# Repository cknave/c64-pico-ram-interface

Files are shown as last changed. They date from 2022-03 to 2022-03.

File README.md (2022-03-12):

# Commodore 64 to Raspberry Pi Pico RAM interface

This project exposes a 16 KiB window of a Raspberry Pi Pico's RAM to a Commodore 64 via the
expansion port. It includes a hardware design and software for the Pico C++ SDK.

<table style="border-collapse: collapse"><tr>
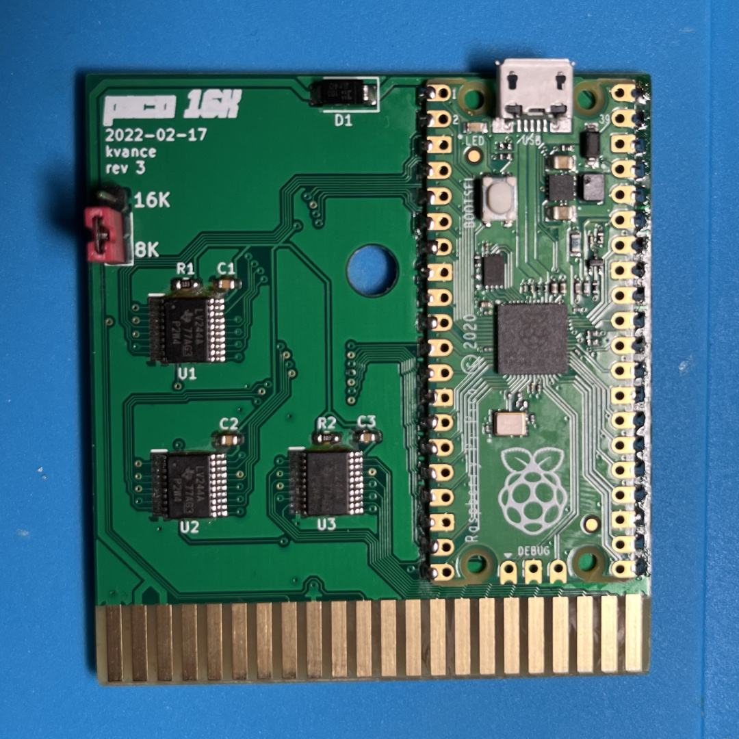
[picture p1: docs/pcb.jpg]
PCB photo
<td><figure>
<figcaption>PCB image</figcaption></figure></td>
<td><figure><a href="https://youtu.be/zC7R9OgKrbg">Demo video thumbnail</a>
<figcaption>Demo video</figcaption></figure>
</tr></table>

## The hardware

**[Schematic PDF](./docs/schematic.pdf)**

Schematic, PCB, and project files are in KiCad 6 format.

5V power from the expansion port is used to power the Pico. As suggested in the Pico datasheet,
a Schottky diode allows the Pico to be connected to powered USB at the same time. 

8-bit buffers bring the 5V logic levels on the address and data bus down to 3.3V to protect
the Pico's GPIO pins. This means that when the C64 reads from the Pico, it's putting a 3.3V
signal on the data bus.  At TTL logic levels, this should be fine.

A switch allows you to toggle between an 8K ROM and a 16K ROM by pulling the /GAME line low.
This loses half the address space, but lets you boot into BASIC.

The tolerances on the PCB design are compatible with [JLCPCB](https://jlcpcb.com/). I ordered
my prototypes from them with ENIG surface finish and gold fingers on a 1.6mm thick board.  You
can get them made much cheaper with HASL, but it will eventually scrape off as you reinsert
the board.

## The firmware

Given a 16 KiB-aligned base address on the Pico's address space, four PIO state machines and
two DMA channels handle reading addresses from the C64 address bus and writing the requested
data to the C64 data bus. The CPU is not needed once this is configured.

To allow the C64 to communicate with the Pico, a 256 byte **command area** is reserved that
will put that byte onto the RX FIFO for the CPU to consume.  The CPU can put any value onto
the TX FIFO to signal that it is ready for more commands.

Between the GPIO pins and the RAM, there are five logical components:

- **address_decoder PIO state machine:** monitors the /ROML and /ROMH lines for reads,
  checks if the address is for the special **command area**, and wakes up either the **read**
  or **command** state machines as needed.  Two copies of this state machine run at the same
  time, monitoring /ROML and /ROMH.
- **read PIO state machine:** reads the address lines, sends the address to DMA, and writes
  the returned data to the data bus
- **command PIO state machine:** reads the low 8 bits of the address, and copies it to the
  RX FIFO for the CPU to handle.  It writes the STATUS register back to the data bus, indicating
  if the CPU is busy or not. The CPU can indicate its readiness by writing any value to the TX FIFO.

  The special value `00` will not be sent to the CPU at all, allowing the C64 to poll the status
  register until the Pico is finished processing a command.
- **DMA channel 1**: write the incoming address to the configuration of DMA channel 2, triggering
  a read
- **DMA channel 2**: copy a byte at the requested RAM address to the read PIO state machine

Read sequence

Command sequence

It's a Rube Goldberg machine, but the Pico's PIO controllers and DMA can do this in well under
the time required by the C64's CPU.

## Further improvements

### Could this work as a 16K ROM and IO ports?

Maybe, but this design is already using all the GPIO pins on the Pico.  Even if you replace
the "input enable" pin (you can probably get away without it), you'll also need to monitor
PHI2.  In my experience, the IO lines are glitchy and you need to make sure that you're actually
in the right part of the clock cycle to use them.

You could try using a shift register to free up a bunch of pins, but you'll waste a lot of
PIO clock cycles shifting all the bits through it.  It might be fast enough to only shift a
couple of bits.

### Could I use all 44 KiB of the available address space?

I think you're definitely in shift register territory at this point, and good luck trying to
decode more than a couple of address prefixes in PIO.  If you actually do this, please contact
me because I want to see it!

## Legal

Distribute under the terms of the BSD 3-clause license.

The [KiCad-RP-Pico footprint](https://github.com/ncarandini/KiCad-RP-Pico) is by
Nicolò Carandini.

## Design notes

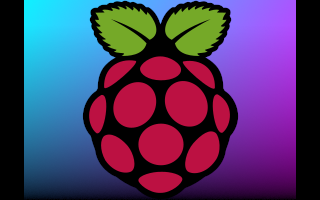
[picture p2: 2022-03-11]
c64-rom/raspi.bmp

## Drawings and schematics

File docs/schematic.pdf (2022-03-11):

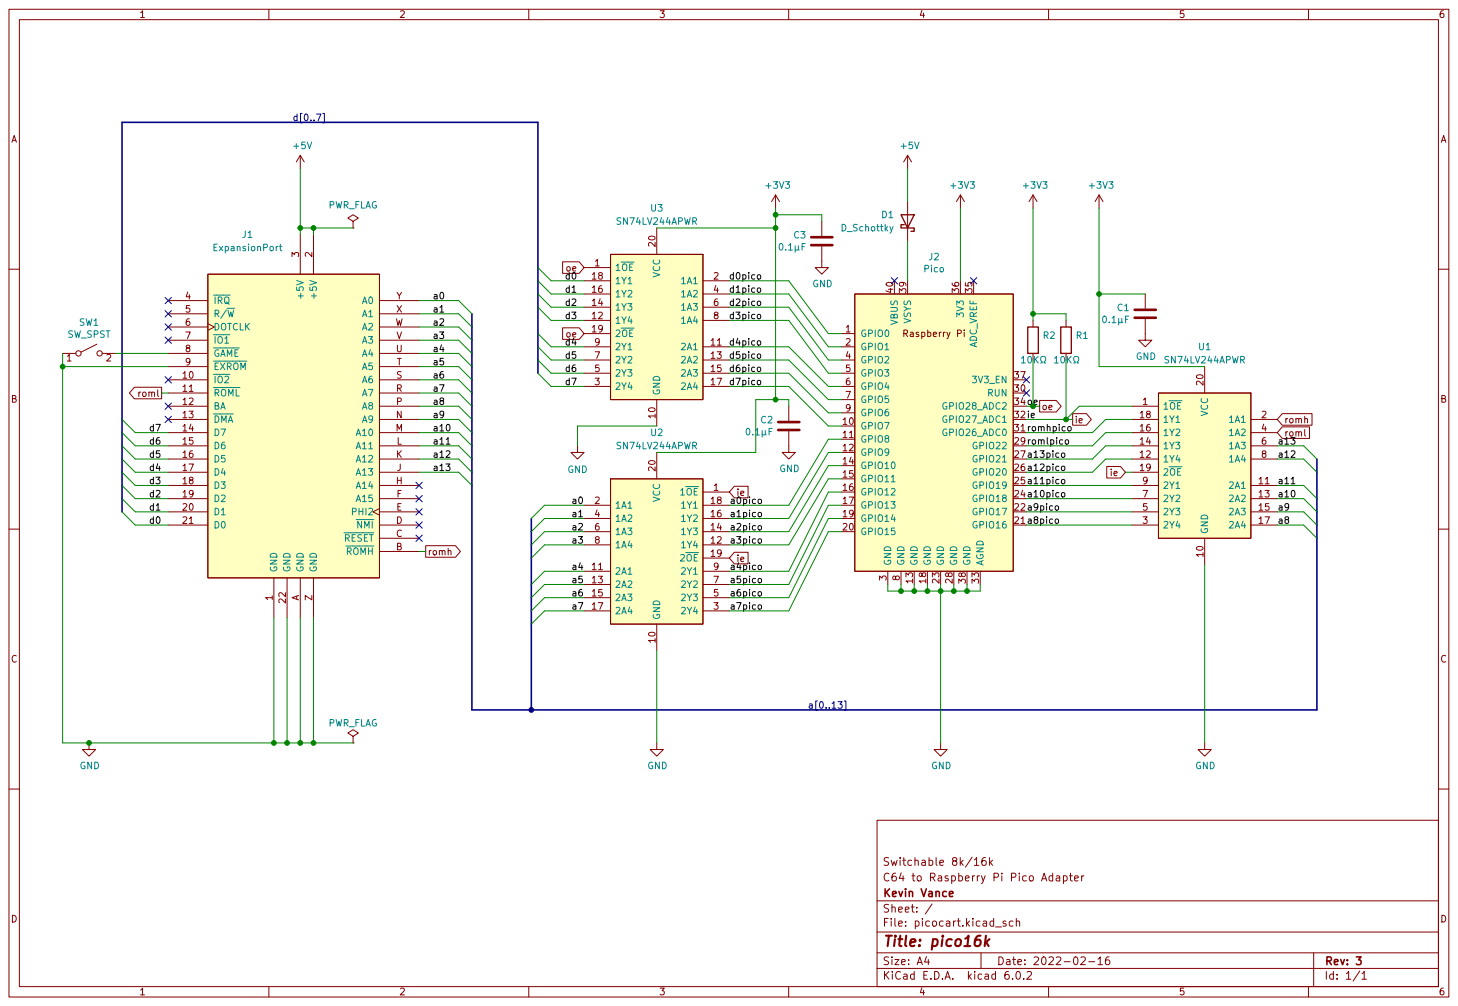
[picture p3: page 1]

3 ~{IRQ} 4 R/~{W} 5 DOTCLK 6 ~{IO1} 7 ~{GAME} 8 ~{EXROM} 9 GND

File: picocart.kicad_sch Sheet: / Kevin Vance C64 to Raspberry Pi Pico Adapter Switchable 8k/16k GND

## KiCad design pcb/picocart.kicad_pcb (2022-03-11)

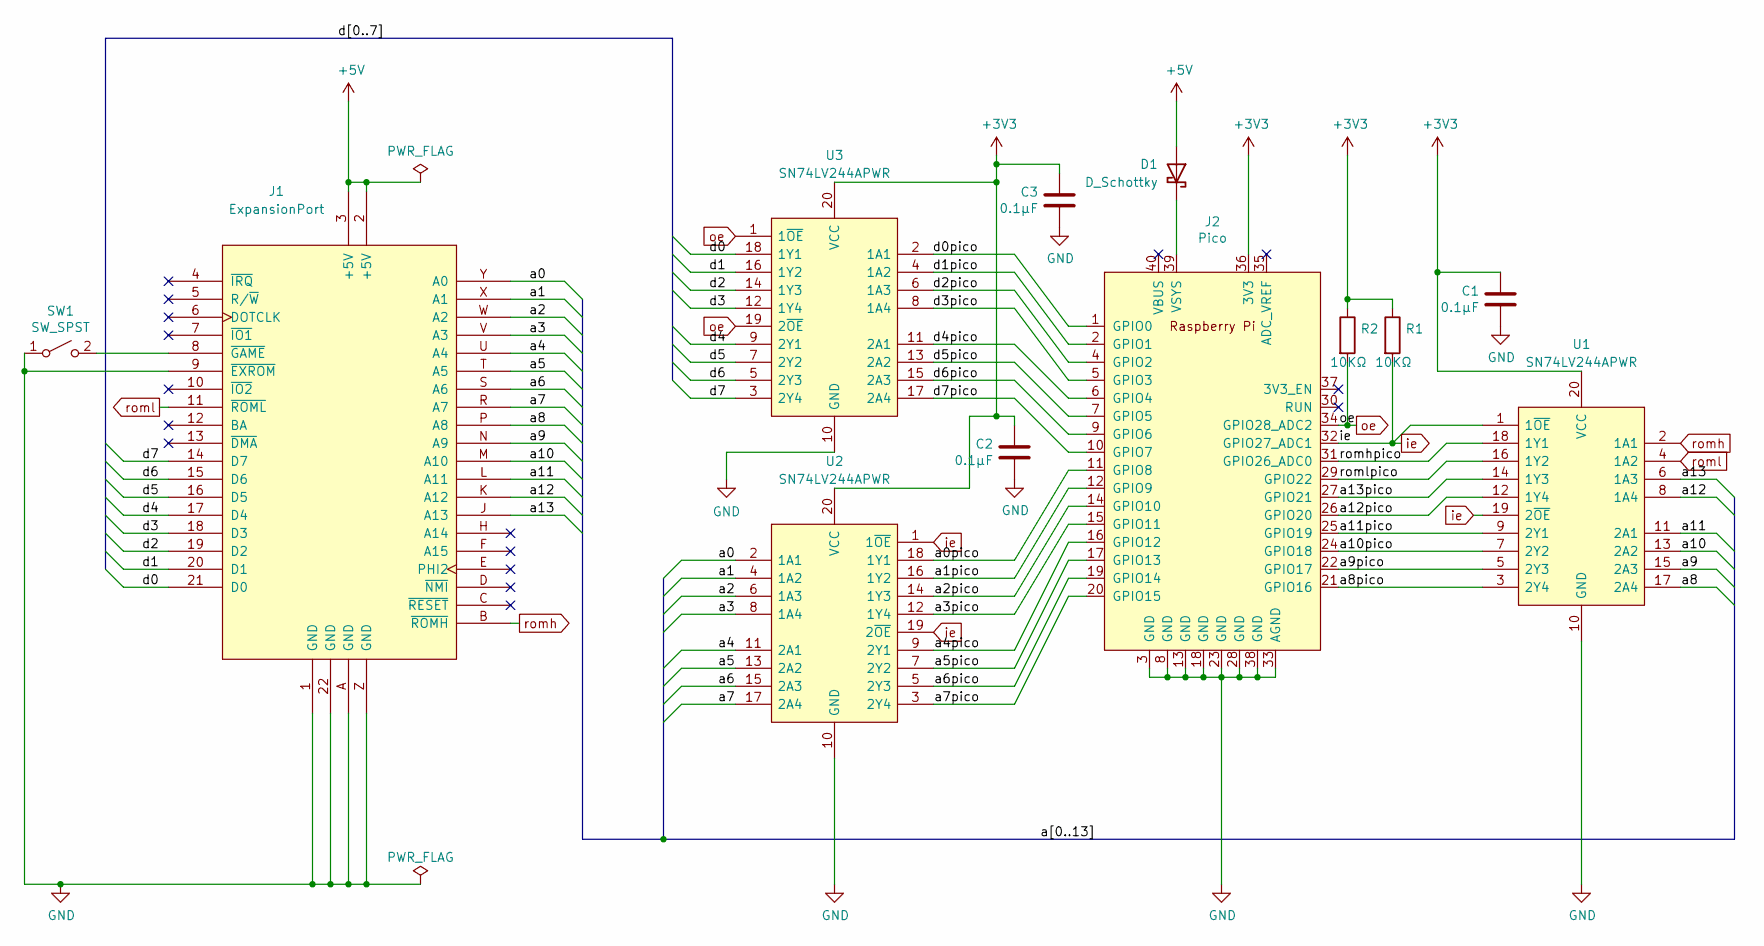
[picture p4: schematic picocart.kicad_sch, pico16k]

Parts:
C1, C2, C3: 0.1μF; C_0603_1608Metric_Pad1.08x0.95mm_HandSolder
D1: D_Schottky; D_SMA
J1: ExpansionPort; C64ExpansionEdgeShort
J2: Pico; RPi_Pico_SMD_TH
R1, R2: 10KΩ; R_0603_1608Metric_Pad0.98x0.95mm_HandSolder
SW1: SW_SPST; PinHeader_1x03_P2.54mm_Vertical
U1, U2, U3: SN74LV244APWR; SOP65P640X120-20N; Mouser Part Number 595-SN74LV244APWR

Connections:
+3V3: C1.1, C2.1, C3.1, J2.36 (3V3), R1.1, R2.1, U1.20 (VCC), U2.20 (VCC), U3.20 (VCC)
+5V: D1.2 (A), J1.2 (+5V), J1.3 (+5V)
/a0: J1.Y (A0), U2.2 (1A1)
/a0pico: J2.11 (GPIO8), U2.18 (1Y1)
/a1: J1.X (A1), U2.4 (1A2)
/a1pico: J2.12 (GPIO9), U2.16 (1Y2)
/a2: J1.W (A2), U2.6 (1A3)
/a2pico: J2.14 (GPIO10), U2.14 (1Y3)
/a3: J1.V (A3), U2.8 (1A4)
/a3pico: J2.15 (GPIO11), U2.12 (1Y4)
/a4: J1.U (A4), U2.11 (2A1)
/a4pico: J2.16 (GPIO12), U2.9 (2Y1)
/a5: J1.T (A5), U2.13 (2A2)
/a5pico: J2.17 (GPIO13), U2.7 (2Y2)
/a6: J1.S (A6), U2.15 (2A3)
/a6pico: J2.19 (GPIO14), U2.5 (2Y3)
/a7: J1.R (A7), U2.17 (2A4)
/a7pico: J2.20 (GPIO15), U2.3 (2Y4)
/a8: J1.P (A8), U1.17 (2A4)
/a8pico: J2.21 (GPIO16), U1.3 (2Y4)
/a9: J1.N (A9), U1.15 (2A3)
/a9pico: J2.22 (GPIO17), U1.5 (2Y3)
/a10: J1.M (A10), U1.13 (2A2)
/a10pico: J2.24 (GPIO18), U1.7 (2Y2)
/a11: J1.L (A11), U1.11 (2A1)
/a11pico: J2.25 (GPIO19), U1.9 (2Y1)
/a12: J1.K (A12), U1.8 (1A4)
/a12pico: J2.26 (GPIO20), U1.12 (1Y4)
/a13: J1.J (A13), U1.6 (1A3)
/a13pico: J2.27 (GPIO21), U1.14 (1Y3)
/d0: J1.21 (D0), U3.18 (1Y1)
/d0pico: J2.1 (GPIO0), U3.2 (1A1)
/d1: J1.20 (D1), U3.16 (1Y2)
/d1pico: J2.2 (GPIO1), U3.4 (1A2)
/d2: J1.19 (D2), U3.14 (1Y3)
/d2pico: J2.4 (GPIO2), U3.6 (1A3)
/d3: J1.18 (D3), U3.12 (1Y4)
/d3pico: J2.5 (GPIO3), U3.8 (1A4)
/d4: J1.17 (D4), U3.9 (2Y1)
/d4pico: J2.6 (GPIO4), U3.11 (2A1)
/d5: J1.16 (D5), U3.7 (2Y2)
/d5pico: J2.7 (GPIO5), U3.13 (2A2)
/d6: J1.15 (D6), U3.5 (2Y3)
/d6pico: J2.9 (GPIO6), U3.15 (2A3)
/d7: J1.14 (D7), U3.3 (2Y4)
/d7pico: J2.10 (GPIO7), U3.17 (2A4)
/romhpico: J2.31 (GPIO26_ADC0), U1.18 (1Y1)
/romlpico: J2.29 (GPIO22), U1.16 (1Y2)
GND: C1.2, C2.2, C3.2, J1.1 (GND), J1.9 (~EXROM), J1.22 (GND), J1.A (GND), J1.Z (GND), J2.3 (GND), J2.8 (GND), J2.13 (GND), J2.18 (GND), J2.23 (GND), J2.28 (GND), J2.33 (AGND), J2.38 (GND), SW1.1 (A), U1.10 (GND), U2.10 (GND), U3.10 (GND)
unnamed: D1.1 (K), J2.39 (VSYS)
unnamed: J1.8 (~GAME), SW1.2 (B)
ie: J2.32 (GPIO27_ADC1), R1.2, U1.1 (1~OE), U1.19 (2~OE), U2.1 (1~OE), U2.19 (2~OE)
oe: J2.34 (GPIO28_ADC2), R2.2, U3.1 (1~OE), U3.19 (2~OE)
romh: J1.B (~ROMH), U1.2 (1A1)
roml: J1.11 (~ROML), U1.4 (1A2)

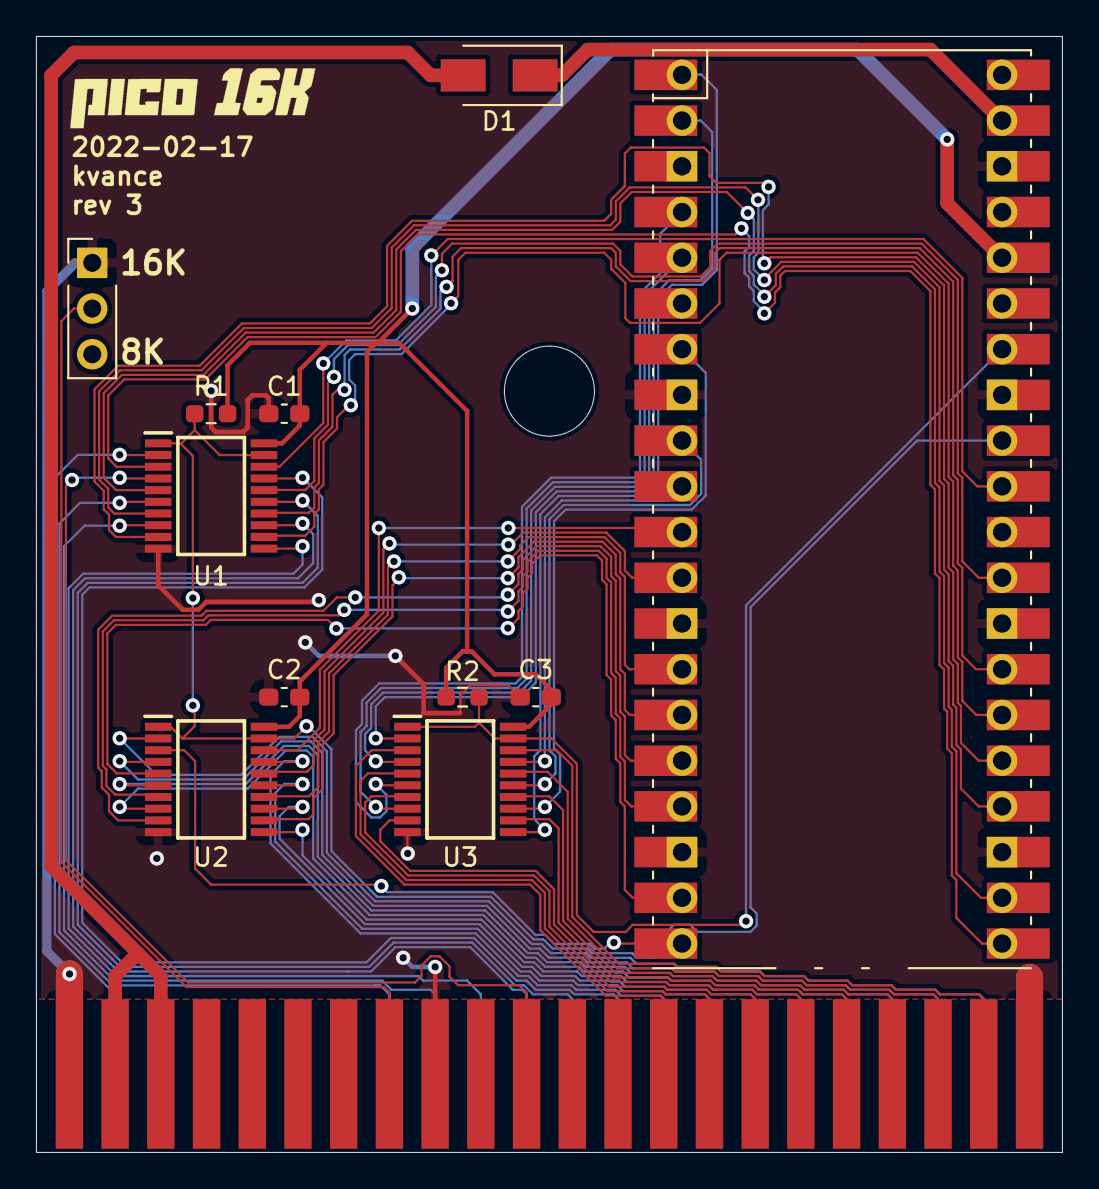
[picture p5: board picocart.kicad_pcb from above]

Board: 2 copper layers, 57.0 x 62.0 mm, 13 parts (0 on the bottom side), 55 nets.

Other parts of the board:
Ref**: Val**; logo

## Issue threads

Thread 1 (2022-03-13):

REU/MOS 8726 DMA controller emulation?

raszpl, 2022-03-13:
https://www.c64-wiki.com/wiki/Expansion_Port
https://rr.pokefinder.org/rrwiki/images/9/90/1750_1764_Service_Schematics.pdf

Afaik _ROML/_ROMH are just address decode helpers to ease cartridge development, and can be swapped for A14/A15.

For complete emulation we will need D0-7, A0-15, R/_W, PHI2, BA, _DMA. 28 IOs. Then we need two more for Data and Address bus level translator (SN74LVC8T245/SN74LVC16T245) direction control.

PICO has 26 IO on edge connector, but you could potentially steal GPIO29/GPIO25 https://peppe8o.com/raspberry-pi-pico-pinout/, still two short :( Chip itself https://datasheets.raspberrypi.com/rp2040/rp2040-datasheet.pdf has 30. https://proto-pic.co.uk/wp-content/uploads/2021/03/RPI-PICO-R3-PUBLIC-SCHEMATIC.pdf
I dont know how viable is stealing GPIO24/GPIO23, but if its possible then we would have all the IO needed for full REU emulation.

cknave, 2022-03-13:
Yeah ROML/ROMH were convenient for this project so I didn't have to monitor R/W, PHI2, and BA.

Are there designs you know of where the Pico's internal GPIOs are used? It looks like GPIO25 couldn't be used as an input for example, since there's an LED on it.

It might be possible to make a design based on the RP2040 only, but that's a lot more complicated. I like the Pico because it already has a bunch of useful parts built in!

I've found that some shift registers (74LVC8T595, 74LV165AD) could be fast enough: 62.5 MHz is as fast as the PIO can generate a clock at the Pico's default clock speed, which is enough to get data in or out in a PHI2 clock pulse. I've only used those for debugging this device though, no idea if they'd be suitable to put on a C64 bus. And bidirectional IO means even more parts and complexity.

Last challenge I can think of is the PIO instruction memory. I'm not familiar with REU capabilities, but you'd probably need to use both PIO units to get everything to fit.

This seems like it's maybe just within the Pico's limits, I'd be very impressed to see it.

raszpl, 2022-03-14:
GPIO25 will be usable after desoldering R3, same with GPIO24 and R1 R10, GPIO29 removing Q1, GPIO23 will require two small trace cuts next to TP4 pad on the underside. After that you will have full hardware control over 30 GPIOs, I presume some pico code will also have to be commented out to not interfere. No need for shift registers.

>REU capabilities

Would be cool to at least get the bare minimum required to get the Sonic C64 REU port running. This requires 256KB of ram, leaving RP2040 XIP and 8KB sram left for firmware (potentially 4kB more if USB is disabled) https://www.lemon64.com/forum/viewtopic.php?t=78945

I have no experience with RP2040 yet, and would love to learn more about PIO ability to handle those kinds of tasks. Im eyeing it as a potential hardware platform for IDE emulation. This requires 120 - 600 ns timings (PIO 4 - PIO 0).

fanoush, 2022-06-06:
hi just a comment regarding gpios mentioned already in closed issue 3  - there is board https://www.aliexpress.com/item/1005003708090298.html which also has GPIOs 24 and 29 available (and extra button on 23) the board is discussed also here https://forums.raspberrypi.com/viewtopic.php?p=1955110#p1955110

Also this board has SPI flash in soic-8 format so it is easier to solder to so it can be also used to steal some more gpios - once bootloader loads code into RAM  the QSPI could be disabled and pins reused as long as CS pin of the flash is kept high.

BTW for bidirectional 5v I/O there is slightly related discussion here https://github.com/q3k/chubby75/issues/37#issuecomment-698011549 the SN74CBT3245APW can be one option

oemsysadm, 2022-10-03:
I would also be interested in this, and have been looking at the Pico for emulating a 1764 REU. It would be ideal if a user building this wouldn't need to source a lot of extra components, and if the PCB would be relatively simple.

If the REU really requires 30 gpio pins, how feasible would it be to put two Picos on the board, have one handle ready and the other write, and connect them to each other via SPI? Maybe we could even get it to then emulate a 1750 REU or a Super CPU with ramcard. It would still be a really cheap device.

Also as an aside, why did you choose to use external flash, rather than use the 2mb flash on the Pico to store roms?

raszpl, 2022-10-04:
Eben recently confirmed pico is 5V tolerant https://hackaday.com/2022/09/25/pi-pico-w-does-pcmcia-gets-this-ibm-pc110-online/#comment-6516402

> Note: the pads themselves are 5V tolerant for input, just not 5V5 tolerant, which is what we’d need them to be to put “5V tolerant” in the data sheet. (Hypothetical) future designs will fix this.
>
> Note also: they’re not (and will never be) 5V *failsafe*, so don’t subject them to 5V without first powering VDDIO.

This is good news as the design could drop level translators _as long as user has C64 5v Overvoltage Saver_. It would make the whole thing just a cheap $1 jlcpcb interposer for $5 pico. This also lowers IO pressure from 30 to 28 pins. reclaiming couple IOs is relatively easy and involves desoldering 3 SMD resistors https://www.reddit.com/r/raspberry_pi/comments/w37gx2/i_freed_up_two_gpios_on_the_raspberry_pi_pico/

as for speed PIO turns out to be much faster than required for RUE emulation.
https://github.com/polpo/picogus directly handling 8MHz ISA
https://github.com/rhulme/picoROM_pio 215nS with no overclocking

cknave, 2022-10-09:
The "2 Picos duct taped together" idea tumbled around in my brain this week. With one Pico for the control signals and the data bus, and another for the address bus, it's not really that unwieldy. And you get another 256K of RAM to use. And without the GPIO pressure, there's room to assert IRQ as well.

It was an interesting enough idea to make a schematic for this weekend. First draft, and these may not be the best chips for the job, just what's in stock today.

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
[c64-pico-reu.pdf](https://github.com/cknave/c64-pico-ram-interface/files/9742449/c64-pico-reu.pdf)

oemsysadm, 2022-10-10:
Looking at the pico pinouts, it seems like you could basically stick 2 picos back to back and have spi0 and spi1 more or less lined up. Does the above hackaday link mean the voltage translators won't even be necessary?

Having a device thats basically 2x picos sandwiched with a pcb between them, and which fits in a std cart enclosure, that can do a 512k REU and maybe a super CPU w. ramcard.. That would be amazing.

Add either a pass through port or the ability to also be a gmod2 or ef3 compatible cartridge, and I think this would be a must have device.

LukaszDziwosz, 2022-11-06:
The schematics looks great. I was personally toying with idea of REU emulation with ESP32 and external RAM but Pico is actually more suitable. I'm very excited that you working on it. This would ignite C64 scene.

raszpl, 2022-11-17:
https://github.com/rumbledethumps/rp6502 pico fast enough for 8MHz 6502 direct buss interfacing https://www.youtube.com/playlist?list=PLvCRDUYedILfHDoD57Yj8BAXNmNJLVM2r

LukaszDziwosz, 2022-11-25:
Guys since Commodore REU was pretty slow what about using 16MB flash on RP2040 USB-C pico clone as RAM?  If that's possible then single pico would be sufficient.

frntc, 2022-12-10:
Hi there,

I'm using latches and multiplexers together with an RPi 3A+/B+ or Zero2 to emulate a REU:
https://github.com/frntc/RAD

LukaszDziwosz, 2022-12-11:
Hi frntc. Given the problems with RPI supply, do you think ESP32 S3 could handle what you did with Zero2?

frntc, 2022-12-11:
I don't have experience with the ESP32s -- in the specs I read about PSRAM with configurable caching behavior, which sounds scary (getting the caching right was already difficult enough on the RPi). How fast is a PSRAM access? The 512k built-in RAM does not sound interesting, you already need the complete 512k for some demos, and you would not be able to watch NUVIEs or BluREU.

My take on this is: RPis will become available (in the past days I've seen RPis 3A+ available in different places). And you can still share the RPi with your Sidekick64 ;-)

LukaszDziwosz, 2022-12-12:
Agreed not worth a hustle

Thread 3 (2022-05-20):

wire a14 a15 instead of romh,roml?

fanoush, 2022-05-20:
I was thinking roml,romh are some simple logic helpers to tell that address ranges are 8000-9f, a000-bf and e000-ff in single bits, if pico could match all address lines  to determine those adress ranges it may not need those romh/roml signal inputs and match 8,9,a,b,e,f directly? then by having all 16 address bits it could also match other address ranges to emulate other features like ram expansion? or even emulate vic/sid to provide better audio/video?

EDIT:
the assumption here is that you are limited on number of total GPIOs so you can't have both.

And BTW there is another  generic RP2040 board available on aliexpress  - the WeAct RP204 board https://www.aliexpress.com/item/1005003708090298.html  which also has  GPIOs 24 and 29 available  (and extra button on 23) https://forums.raspberrypi.com/viewtopic.php?p=1955110#p1955110

fanoush, 2022-06-06:
already discussed in  #1 so closing

Closed 2022-06-06.

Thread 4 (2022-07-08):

Possible use with c128 (at c128 mode)

odflor, 2022-07-08:
Your idea of use the pico as a Commodore ROM and in some way as a co-processor is exacly I was looking for a long time.

Mi idea is to bring new software for the c128 as cheap, and painless possible, and Your project have so much potencial por this.

There is a way to make it work on a c128 (on c128 mode)?

cknave, 2022-07-09:
I'm not familiar with the C128, but looking at http://blog.worldofjani.com/?p=1600:

> When a C128 is booted, a cartridge presence is checked. First it checks if GAME or EXROM lines are low. If this is the case, a C64 mode cartridge is connected and the machine starts in C64 mode. Otherwise the C128 memory is checked for an identifier(“CBM”) string at $8007 and $c007, this is done both for the external and internal slots.

It looks like all we'd need to do is disconnect the GAME and EXROM lines, and set the appropriate signature in the pico's RAM. For this design you'd have to physically cut the GAME and EXROM traces, but a new revision could add a jumper for it.

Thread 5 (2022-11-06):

Need BOM

detlefgrohs, 2022-11-06:
I am really interested in this project and have just ordered a set of boards so that I can build 1 for myself. I would have preferred to order the boards populated but I can order the parts separately and solder the surface mount components. A BOM would help with ordering the boards. Also I was having a hard time finding the actual components on the JLCPCB site so I decided to just get the boards and then order the parts later if I didn't have the resistors and capacitors already.

I was also wanting to reach out and see what I can do to contribute to this project. I have recently gotten back into retro computing and have obtained both an actual C64 and C128 that I have been doing some assembly development on. I had the idea earlier to see about using a Raspberry Pi to interface to a C64 and started to do some research into what existing projects there were and ran across your use of the Pico. I have done some development with the Pico and it is a brilliant solution to the interface that I am thinking about.

Also, I saw the 2 Pico solution that would allow for more capabilities, and I am interested in that also. I also saw another project where a Raspberry Pi was used to generate HDMI directly from a cartridge port.

cknave, 2022-11-07:
Would something like this work? [picocart.csv](https://github.com/cknave/c64-pico-ram-interface/files/9948164/picocart.csv)

KiCad has a lot of BOM output generators, this one is from `bom_csv_grouped_by_value.py`. If that looks useful, I'll add it to the repo.

I'll be interested to see if it works on the C128. Are they PAL or NTSC machines? As far as I know, this has only been tested on NTSC (though I can't imagine PAL would cause a problem).

detlefgrohs, 2022-11-07:
The BOM is a start I will see if I can get exact part numbers and specifications. I think I was trying to find the exact parts @ JLCPCB so they could pre-populate the board. I am new to ordering the boards prepopulated so wanted I make sure I got everything exactly right. If you are thinking of moving forward with the 2 Pico solution, I would be interested in helping with the development of that and I can help by paying for and ordering the boards and testing the boards. This solution would allow for some great solutions with the available add-ons to the Pico that are available: LCD display, HDMI output etc... I could see a lot of different ideas going out of this. I am also involved with the Foenix system and have a Mega65 on order so 6502, 4510 and the 65816 processors so I am improving my assembly skills.

I will let you know when I get the blank boards and start populating them...

The C128 is NTSC (rasterOverscan = $06) and the C64 is PAL (rasterOverscan is $37). I found some assembly that would determine the machine type through code by getting the rasterOverscan. I made this into a routine so I could the timing so that I could use the jiffyTimer to time executions:

FUNCTION GetRasterOverflow() : byte;
BEGIN
	ASM
			SEI
System_GetRasterOverflow_WaitBMI:
			LDA $D011
			BMI System_GetRasterOverflow_WaitBMI

System_GetRasterOverflow_WaitBPL:
			LDA $D011
			BPL System_GetRasterOverflow_WaitBPL

System_GetRasterOverflow_WaitNoBPL:
			LDA $D012
			BIT $D011
			BPL System_GetRasterOverflow_WaitDone
			STA System_rasterOverflow
			BMI System_GetRasterOverflow_WaitNoBPL

System_GetRasterOverflow_WaitDone:
			CLI
	END;

	RETURNVALUE(rasterOverflow);
END;

cknave, 2022-11-07:
For the ICs, the exact model doesn't matter so much. I used TI SN74LV244APWRG3, SN74LV244APWRG4, SN74LV244ATPWR; as well as Nexperia 74LV244APWJ when I was prototyping these.

I do plan on spending some time on the 2 pico idea at some point soon. I have a new design I'll put in a new repo once I can do some testing.

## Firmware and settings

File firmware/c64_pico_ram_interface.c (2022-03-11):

// vim: ts=4:sw=4:sts=4:et
#include <malloc.h>
#include <stdio.h>
#include <string.h>

#include "hardware/dma.h"
#include "hardware/irq.h"
#include "hardware/pio.h"
#include "pico/binary_info.h"
#include "pico/stdlib.h"

#include "address_decoder.pio.h"
#include "command.pio.h"
#include "loader_rom.h"
#include "raspi.h"
#include "read.pio.h"

// Blink error codes
const uint ERR_ADD_DECODER_PROGRAM = 1;
const uint ERR_DECODER_PROGRAM_SM = 2;
const uint ERR_ADD_READ_PROGRAM = 3;
const uint ERR_READ_PROGRAM_SM = 4;
const uint ERR_ADD_COMMAND_PROGRAM = 5;
const uint ERR_COMMAND_PROGRAM_SM = 6;

// Pin assignments
// Note: PIO programs assume the pins are in this order!
const uint PIN_D0 = 0;
const uint PIN_D1 = 1;
const uint PIN_D2 = 2;
const uint PIN_D3 = 3;
const uint PIN_D4 = 4;
const uint PIN_D5 = 5;
const uint PIN_D6 = 6;
const uint PIN_D7 = 7;
const uint PIN_A0 = 8;
const uint PIN_A1 = 9;
const uint PIN_A2 = 10;
const uint PIN_A3 = 11;
const uint PIN_A4 = 12;
const uint PIN_A5 = 13;
const uint PIN_A6 = 14;
const uint PIN_A7 = 15;
const uint PIN_A8 = 16;
const uint PIN_A9 = 17;
const uint PIN_A10 = 18;
const uint PIN_A11 = 19;
const uint PIN_A12 = 20;
const uint PIN_A13 = 21;
const uint PIN_ROML = 22;
const uint PIN_ROMH = 26;
const uint PIN_IE = 27;
const uint PIN_OE = 28;

// PIO IRQ bits
const uint PIO_IRQ_ON_READ = 1;

// NUFLI offset in our ROM area
const uint NUFLI_OFFSET = 0x400;
const uint NUFLI_WINDOW_SIZE = 0x400;


typedef enum {
    CMD_NEXT_PAGE = 0x01,   // Advance the NUFLI window to the next 1K
    CMD_SLEEP = 0x02,       // Test a slow command that sleeps for 5 seconds
} command_t;

const uint BLINK_MS = 100;


void on_pio_irq();
void do_a_blink();
void read_dma_init(PIO pio, uint sm, char *base_address);
void errorblink(int code) __attribute__((noreturn));
static inline void init_output_pin(uint pin, bool value);


#pragma clang diagnostic push
#pragma ide diagnostic ignored "EndlessLoop"

int main() {
    bi_decl(bi_1pin_with_name(PIN_D0, "data output pin 0 (U3 pin 2)"))
    bi_decl(bi_1pin_with_name(PIN_D1, "data output pin 1 (U3 pin 4)"))
    bi_decl(bi_1pin_with_name(PIN_D2, "data output pin 2 (U3 pin 6)"))
    bi_decl(bi_1pin_with_name(PIN_D3, "data output pin 3 (U3 pin 8)"))
    bi_decl(bi_1pin_with_name(PIN_D4, "data output pin 4 (U3 pin 11)"))
    bi_decl(bi_1pin_with_name(PIN_D5, "data output pin 5 (U3 pin 13)"))
    bi_decl(bi_1pin_with_name(PIN_D6, "data output pin 6 (U3 pin 15)"))
    bi_decl(bi_1pin_with_name(PIN_D7, "data output pin 7 (U3 pin 17)"))
    bi_decl(bi_1pin_with_name(PIN_A0, "address input pin 0 (U2 pin 18)"))
    bi_decl(bi_1pin_with_name(PIN_A1, "address input pin 1 (U2 pin 16)"))
    bi_decl(bi_1pin_with_name(PIN_A2, "address input pin 2 (U2 pin 14)"))
    bi_decl(bi_1pin_with_name(PIN_A3, "address input pin 3 (U2 pin 12)"))
    bi_decl(bi_1pin_with_name(PIN_A4, "address input pin 4 (U2 pin 9)"))
    bi_decl(bi_1pin_with_name(PIN_A5, "address input pin 5 (U2 pin 7)"))
    bi_decl(bi_1pin_with_name(PIN_A6, "address input pin 6 (U2 pin 5)"))
    bi_decl(bi_1pin_with_name(PIN_A7, "address input pin 7 (U2 pin 3)"))
    bi_decl(bi_1pin_with_name(PIN_A8, "address input pin 8 (U1 pin 3)"))
    bi_decl(bi_1pin_with_name(PIN_A9, "address input pin 9 (U1 pin 5)"))
    bi_decl(bi_1pin_with_name(PIN_A10, "address input pin 10 (U1 pin 7)"))
    bi_decl(bi_1pin_with_name(PIN_A11, "address input pin 11 (U1 pin 9)"))
    bi_decl(bi_1pin_with_name(PIN_A12, "address input pin 12 (U1 pin 12)"))
    bi_decl(bi_1pin_with_name(PIN_A13, "address input pin 13 (U1 pin 14)"))
    bi_decl(bi_1pin_with_name(PIN_ROML, "ROML input pin (U1 pin 16)"))
    bi_decl(bi_1pin_with_name(PIN_ROMH, "ROMH input pin (U1 pin 18)"))
    bi_decl(bi_1pin_with_name(PIN_OE, "\"input enable\" output pin (U1 and U2, pins 1 and 19)"))
    bi_decl(bi_1pin_with_name(PIN_OE, "\"output enable\" output pin (U3 pins 1 and 19)"))

    // Start with I/O to the C64 disabled
    init_output_pin(PIN_OE, true);  // high = disabled
    init_output_pin(PIN_IE, true);  // high = disabled

    stdio_usb_init();
    printf("\n\n\n");
    printf("C64 pico ram interface %s\n", PICO_PROGRAM_VERSION_STRING);

    // Data exposed by the ROM window must be aligned by 16 kbytes so we can use the least
    // significant bits of its address for A0-A13
    const int rom_size = 16384;
    char *rom_data = memalign(rom_size, rom_size);

    // Initialize the ROM area with our loader ROM
    memcpy(rom_data, loader_rom, sizeof(loader_rom));

    // Initialize the NUFLI area of our ROM with the first 1KB
    int raspi_offset = 0;
    memcpy(rom_data + NUFLI_OFFSET, raspi, NUFLI_WINDOW_SIZE);

    PIO pio = pio0;

    // Address decoder: waits for ROMH/ROML line to be set low, and determines whether the address
    // to read is a command or a normal ROM read.  Each state machine monitors one ROM line.
    if(!pio_can_add_program(pio, &address_decoder_program)) {
        errorblink(ERR_ADD_DECODER_PROGRAM);
    }
    uint address_decoder_offset = pio_add_program(pio, &address_decoder_program);
    uint address_decoder_sm[2];
    const uint rom_pins[2] = {PIN_ROMH, PIN_ROML};
    for(int i = 0; i < 2; i++) {
        address_decoder_sm[i] = pio_claim_unused_sm(pio, true);
        if(address_decoder_sm[i] == -1) {
            errorblink(ERR_DECODER_PROGRAM_SM + i);
        }
        address_decoder_program_init(
                pio,
                address_decoder_sm[i],
                address_decoder_offset,
                PIN_A8,
                rom_pins[i],
                PIN_OE);
    }

    // Read handler: send rom_data value over D0..D7 when the C64 reads from ROML or ROMH
    if(!pio_can_add_program(pio, &read_program)) {
        errorblink(ERR_ADD_READ_PROGRAM);
    }
    uint read_offset = pio_add_program(pio, &read_program);
    uint read_sm = pio_claim_unused_sm(pio, true);
    if(read_sm == -1) {
        errorblink(ERR_READ_PROGRAM_SM);
    }
    read_program_init(
            pio,
            read_sm,
            read_offset,
            PIN_D0,
            PIN_A0,
            PIN_OE,
            rom_data);
    read_dma_init(pio, read_sm, rom_data);

    // Command handler: put command NN on the FIFO when the CPU reads from address $BFNN
    if(!pio_can_add_program(pio, &command_program)) {
        errorblink(ERR_ADD_COMMAND_PROGRAM);
    }
    uint command_offset = pio_add_program(pio, &command_program);
    uint command_sm = pio_claim_unused_sm(pio, true);
    if(command_sm == -1) {
        errorblink(ERR_COMMAND_PROGRAM_SM);
    }
    command_program_init(
            pio,
            command_sm,
            command_offset,
            PIN_A0,
            PIN_D0,
            PIN_OE);

    // Set up blinkenlight pin
    gpio_init(PICO_DEFAULT_LED_PIN);
    gpio_set_dir(PICO_DEFAULT_LED_PIN, GPIO_OUT);
    gpio_put(PICO_DEFAULT_LED_PIN, 0);

    // Install IRQ handler for blinkenlights on read
    // Per the RP2040 datasheet (PIO: IRQ0_INTE Register, p. 399)
    // state machine enable flags start at bit 8
    pio->inte0 = 1 << (8 + address_decoder_sm[0]);
    irq_set_exclusive_handler(PIO0_IRQ_0, on_pio_irq);
    irq_set_enabled(PIO0_IRQ_0, true);

    // READY!  Open the floodgates!
    gpio_put(PIN_IE, false);  // low = enabled

    printf("Address decoder ROMH sm: %d\n", address_decoder_sm[0]);
    printf("Address decoder ROML sm: %d\n", address_decoder_sm[1]);
    printf("Read sm: %d\n", read_sm);
    printf("Command sm: %d\n", command_sm);
    printf("Pico RAM window start: 0x%08X\n", (uint)rom_data);
    printf("First 8 bytes of ROM: %02X %02X %02X %02X %02X %02X %02X %02X\n",
           rom_data[0], rom_data[1], rom_data[2], rom_data[3], rom_data[4], rom_data[5],
           rom_data[6], rom_data[7]);
    printf("First 8 bytes of NUFLI: %02X %02X %02X %02X %02X %02X %02X %02X\n",
           ((char *)(rom_data + NUFLI_OFFSET))[0], ((char *)(rom_data + NUFLI_OFFSET))[1],
           ((char *)(rom_data + NUFLI_OFFSET))[2], ((char *)(rom_data + NUFLI_OFFSET))[3],
           ((char *)(rom_data + NUFLI_OFFSET))[4], ((char *)(rom_data + NUFLI_OFFSET))[5],
           ((char *)(rom_data + NUFLI_OFFSET))[6], ((char *)(rom_data + NUFLI_OFFSET))[7]);
    printf("ROM address: $8000\n");
    printf("Command address prefix: $%04X\n", 0x8000 + (address_decoder_COMMAND_PREFIX << 8));

    const char spinner[] = {'|', '/', '-', '\\'};
    while(true) {
	    pio_sm_put(pio, command_sm, 1);  // tell the command program we're ready
        printf("\nReady for command %c", spinner[0]);

        uint64_t last_hb = time_us_64();
        uint spinner_pos = 0;
        do {
            uint64_t now = time_us_64();
            if(now - last_hb >= 1000000 / sizeof(spinner)) {
                printf("\b%c", spinner[spinner_pos]);
                spinner_pos++;
                if(spinner_pos == sizeof(spinner)) {
                    spinner_pos = 0;
                }
                last_hb = now;
            }
        } while(pio_sm_is_rx_fifo_empty(pio, command_sm));
        printf("\b \n");

        uint command = pio_sm_get_blocking(pio, command_sm);
        printf("Got command %08X\n", command);

        switch(command) {
            case CMD_NEXT_PAGE:
                raspi_offset += NUFLI_WINDOW_SIZE;
                if(raspi_offset >= sizeof(raspi)) {
                    raspi_offset = 0;
                }
                printf("NUFLI start is now %02X\n", (uint)raspi_offset);
                memcpy(rom_data + NUFLI_OFFSET, raspi + raspi_offset, NUFLI_WINDOW_SIZE);
                printf("First 8 bytes: %02X %02X %02X %02X %02X %02X %02X %02X\n", ((char *)(rom_data + NUFLI_OFFSET))[0], ((char *)(rom_data + NUFLI_OFFSET))[1], ((char *)(rom_data + NUFLI_OFFSET))[2], ((char *)(rom_data + NUFLI_OFFSET))[3], ((char *)(rom_data + NUFLI_OFFSET))[4], ((char *)(rom_data + NUFLI_OFFSET))[5], ((char *)(rom_data + NUFLI_OFFSET))[6], ((char *)(rom_data + NUFLI_OFFSET))[7]);
                break;

        	case CMD_SLEEP:
        		printf("Sleeping\n");
		        sleep_ms(5000);
		        printf("Done\n");
		        break;
        }
    }
}

#pragma clang diagnostic pop


// Set up DMA channels for handling reads
void read_dma_init(PIO pio, uint sm, char *base_address) {
    // Read channel: copy requested byte to TX fifo (source address set by write channel below)
    uint read_channel = 0;
    dma_channel_claim(read_channel);

    dma_channel_config read_config = dma_channel_get_default_config(read_channel);
    channel_config_set_read_increment(&read_config, false);
    channel_config_set_write_increment(&read_config, false);
    channel_config_set_dreq(&read_config, pio_get_dreq(pio, sm, true));
    channel_config_set_transfer_data_size(&read_config, DMA_SIZE_8);

    dma_channel_configure(read_channel,
                          &read_config,
                          &pio->txf[sm], // write to TX fifo
                          base_address,  // read from base address (overwritten by write channel)
                          1,             // transfer count
                          false);        // start later

    // Write channel: copy address from RX fifo to the read channel's READ_ADDR_TRIGGER
    uint write_channel = 1;
    dma_channel_claim(write_channel);
    dma_channel_config write_config = dma_channel_get_default_config(write_channel);
    channel_config_set_read_increment(&write_config, false);
    channel_config_set_write_increment(&write_config, false);
    channel_config_set_dreq(&write_config, pio_get_dreq(pio, sm, false));
    channel_config_set_transfer_data_size(&write_config, DMA_SIZE_32);

    volatile void *read_channel_addr = &dma_channel_hw_addr(read_channel)->al3_read_addr_trig;
    dma_channel_configure(write_channel,
                          &write_config,
                          read_channel_addr, // write to read_channel READ_ADDR_TRIGGER
                          &pio->rxf[sm],     // read from RX fifo
                          0xffffffff,        // do many transfers
                          true);             // start now
}

// Timer for on_clear
alarm_id_t clear_read_alarm = -1;

// Clear the LED after it's blunk
int64_t on_clear_led(alarm_id_t alarm_id, void *user_data) {
    gpio_put(PICO_DEFAULT_LED_PIN, 0);
    clear_read_alarm = -1;
    return 0;
}

// On IRQ0 (command received), blink the LED
void on_pio_irq() {
    PIO pio = pio0;
    if(pio->irq & PIO_IRQ_ON_READ) {
        hw_clear_bits(&pio->irq, PIO_IRQ_ON_READ);
        do_a_blink();
    }
}

void do_a_blink() {
    // Turn on the LED
    gpio_put(PICO_DEFAULT_LED_PIN, 1);

    // If we already had a timer to turn it off, cancel it
    if(clear_read_alarm > 0) {
        cancel_alarm(clear_read_alarm);
    }

    // Turn off the LED later
    clear_read_alarm = add_alarm_in_ms(BLINK_MS, on_clear_led, NULL, true);
}

// Repeat a series of blinks forever
void errorblink(int code) {
    gpio_init(PICO_DEFAULT_LED_PIN);
    gpio_set_dir(PICO_DEFAULT_LED_PIN, GPIO_OUT);
    while(true) {
        for(int i = 0; i < code; i++) {
            gpio_put(PICO_DEFAULT_LED_PIN, 1);
            sleep_ms(333);
            gpio_put(PICO_DEFAULT_LED_PIN, 0);
            sleep_ms(333);
        }
        sleep_ms(667);
    }
}

// Initialize an output GPIO pin and set its value
void init_output_pin(uint pin, bool value) {
    gpio_init(pin);
    gpio_set_dir(pin, true);  // output direction
    gpio_put(pin, value);
}

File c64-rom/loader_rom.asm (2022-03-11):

.file [name="loader_rom.bin", type="bin", segments="Code,CopySource,CommandArea"]

.label nufli_dest = $2000   // NUFLI destination start
.label nufli_exec = $3000   // NUFLI displayer entry point
.const NUFLI_SIZE = $5a00   // unpacked NUFLI size (size of raspi.bin)
.const NUM_1K_NUFLI_BLOX = floor(NUFLI_SIZE/1024)  // number of full 1K NUFLI blocks
                                                   // (remainder is not counted)

//
// Zero-page pointers (used to copy to different offsets into nufli_dest)
//
.label dest_ptr1 = $f8
.label dest_ptr2 = $fa
.label dest_ptr3 = $fc
.label dest_ptr4 = $fe

//
// 1k window to copy NUFLI from
//
.segmentdef CopySource [min=$8400, max=$87ff]
.label copy_source = $8400


//
// 256 byte window to send commands by reading from
//
.segmentdef CommandArea [min=$9e00, max=$9eff]
.label command_area = $9e00
.const CMD_GET_STATUS = 0
.const CMD_NEXT_PAGE = 1


.segment Code [start=$8000]

*=$8000                         // cartridge header
.word start                     // start address
.word start                     // NMI ISR address
.encoding "petscii_mixed"       
.text "CBM80"                   // cartridge signature
.encoding "screencode_upper"

start:  jsr $ff81               // kernal: initialize VIC-II
        jsr $ff84               // kernal: initialize CIA

        // show a black screen while we load the NUFLI data
        lda #0
        sta $d020               // black border
        sta $d021               // black background
        lda #' '                // clear with spaces
        ldx #0
clear:  sta $0400, x
        sta $0500, x
        sta $0600, x
        sta $0700, x
        dex
        bne clear

        ldx #NUM_1K_NUFLI_BLOX  // copy the NUFLI 1 KB at a time
        lda #<nufli_dest        // put copy destinations in $f8,$fa,$fc,$fe
        sta dest_ptr1
        sta dest_ptr2
        sta dest_ptr3
        sta dest_ptr4
        lda #>nufli_dest
        sta dest_ptr1 + 1
        lda #>(nufli_dest + $100)
        sta dest_ptr2 + 1
        lda #>(nufli_dest + $200)
        sta dest_ptr3 + 1
        lda #>(nufli_dest + $300)
        sta dest_ptr4 + 1

        ldy #0
copy1k: lda command_area + CMD_GET_STATUS
        sta $d020               // flash border if the pico's cpu is busy
        bne copy1k              // loop until status is not busy
        lda copy_source, y
        sta (dest_ptr1), y
        lda copy_source + $100, y
        sta (dest_ptr2), y
        lda copy_source + $200, y
        sta (dest_ptr3), y
        lda copy_source + $300, y
        sta (dest_ptr4), y
        iny
        bne copy1k

        lda command_area + CMD_NEXT_PAGE    // advance the source window by 1 KB
        clc
        lda #4                              // advance the dest addrs by 1 KB (high byte of #$400)
        adc dest_ptr1 + 1
        sta dest_ptr1 + 1
        lda #4
        adc dest_ptr2 + 1
        sta dest_ptr2 + 1
        lda #4
        adc dest_ptr3 + 1
        sta dest_ptr3 + 1
        lda #4
        adc dest_ptr4 + 1
        sta dest_ptr4 + 1

        dex                     // loop copying whole KBs
        bne copy1k

        // copy the remaining data 256 bytes at a time
        // (could be optimized by trying 768 at a time, then 512, then up to 256)
        ldx #0
.const BYTES_LEFT = NUFLI_SIZE & $03ff
.for(var i = 0; i < BYTES_LEFT; i += 256) {
        .if (BYTES_LEFT - i < 256) {
                ldx #(BYTES_LEFT - i)
        }
copy:   lda copy_source + i, x
        sta nufli_dest + NUM_1K_NUFLI_BLOX*1024 + i, x
        inx
        bne copy
}
        jmp nufli_exec          // Finished copying! Execute!
